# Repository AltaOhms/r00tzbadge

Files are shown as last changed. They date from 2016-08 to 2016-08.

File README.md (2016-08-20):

# r00tz badge 2016
Example code and eagle files for r00tz badge 2016

##To Solder the Badge
Under the [HookupGuide](https://github.com/HelloTechie/r00tzbadge/tree/master/HookupGuide) folder has the hook-up soldering guide.

##BOM - Bill of Materials

###[SparkFun](https://www.sparkfun.com)

* [SparkFun Redstick](https://www.sparkfun.com/products/13741)
* [LED Array](https://www.sparkfun.com/products/13795)
* [IR LED](https://www.sparkfun.com/products/9349)
* [4x Arduino Stackable Header - 6 pin](https://www.sparkfun.com/products/9280)
* [2x Momentary Pushbutton Switch - 12mm Square](https://www.sparkfun.com/products/9190)
* [BONUS: Thumb Joystick](https://www.sparkfun.com/products/9032)
* [BONUS: Joystick PCB](https://www.sparkfun.com/products/9110)

###[Pololu](https://www.pololu.com)

* [Battery Holder](https://www.pololu.com/product/1160)
* [Breakaway headers](https://www.pololu.com/product/965)

###[Digikey](http://www.digikey.com/) 

* [Standard Headers](http://www.digikey.com/product-detail/en/sullins-connector-solutions/PPTC121LFBN-RC/S6100-ND/807231)
* [IC IR RCVR MOD 38KHZ DOME RADIAL](http://www.digikey.com/scripts/DkSearch/dksus.dll?Detail&itemSeq=201968569&uq=636052976367495774)
* [56 Resistor](http://www.digikey.com/product-detail/en/stackpole-electronics-inc/CFM12JT56R0/S56HCT-ND/2617631)
* [330 ohm Resistor](http://www.digikey.com/product-detail/en/yageo/CFR-12JB-52-330R/330EBK-ND/4009)
* [ESD Bags](http://www.digikey.com/product-detail/en/scs/10046/SCP313-ND/1621588)

###Coding time!

####Redstick - An Arduino in a small form factor!
The Redstick [guide](https://learn.sparkfun.com/tutorials/redstick-hookup-guide?_ga=1.155838777.304927311.1426541708) is jammed packed with infomation on pin outs and how to get started coding!

If you are using Windows, you will need to install [FTDI Drivers](https://learn.sparkfun.com/tutorials/how-to-install-ftdi-drivers). 

####Arduino IDE
You will need to download the [Arduino IDE here](https://www.arduino.cc/en/Main/Software). Arduino is completely free and open source! What is great about the Arduino is that the community is huge and there is tons of example code and guides to help jump start your own projects. Included in this repo is [r00tz example code and libraries](https://github.com/HelloTechie/r00tzbadge/tree/master/Libraries). To learn how to add the r00tz arduino libraries, please follow this [tutorial](https://learn.sparkfun.com/tutorials/installing-an-arduino-library?_ga=1.197370157.304927311.1426541708).

Happy hacking!

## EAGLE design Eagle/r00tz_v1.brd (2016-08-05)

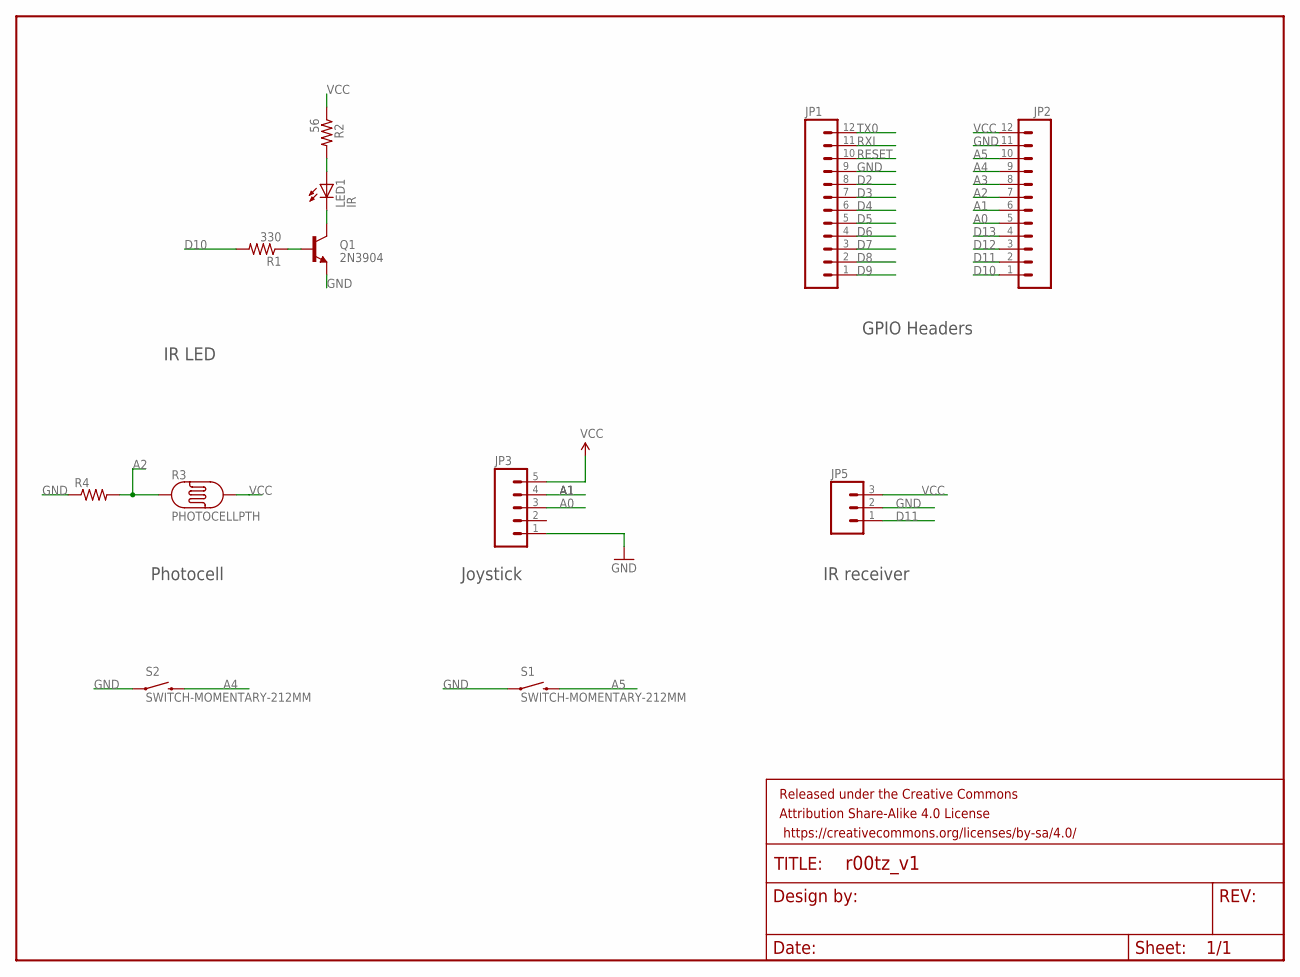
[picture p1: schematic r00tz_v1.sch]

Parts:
FRAME1: FRAME-LETTER; CREATIVE_COMMONS
JP1, JP2: M12PTH; 1X12
JP3: M05PTH; 1X05
JP5: M03PTH; 1X03
LED1: IR; LED5MM
Q1: 2N3904; TO-92
R1: 330; AXIAL-0.3
R2: 56; AXIAL-0.3
R3: PHOTOCELLPTH; PHOTOCELL
R4: 10KOHM-1/6W-5%(PTH)KIT; AXIAL-0.3-KIT
S1, S2: SWITCH-MOMENTARY-212MM; TACTILE-PTH-12MM

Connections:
A0: JP2.5, JP3.3
A1: JP2.6, JP3.4
A2: JP2.7, R3.1, R4.P$2 (2)
A3: JP2.8
A4: JP2.9, S2.3 (2)
A5: JP2.10, S1.3 (2)
D2: JP1.8
D3: JP1.7
D4: JP1.6
D5: JP1.5
D6: JP1.4
D7: JP1.3
D8: JP1.2
D9: JP1.1
D10: JP2.1, R1.P$2 (2)
D11: JP2.2, JP5.1
D12: JP2.3
D13: JP2.4
GND: JP1.9, JP2.11, JP3.1, JP5.2, Q1.1 (E), R4.P$1 (1), S1.1, S2.1
unnamed: LED1.K (C), Q1.3 (C)
unnamed: Q1.2 (B), R1.P$1 (1)
unnamed: LED1.A, R2.P$2 (2)
RESET: JP1.10
RXI: JP1.11
TX0: JP1.12
VCC: JP2.12, JP3.5, JP5.3, R2.P$1 (1), R3.2

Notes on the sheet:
GPIO Headers
Joystick
Photocell
IR LED
IR receiver

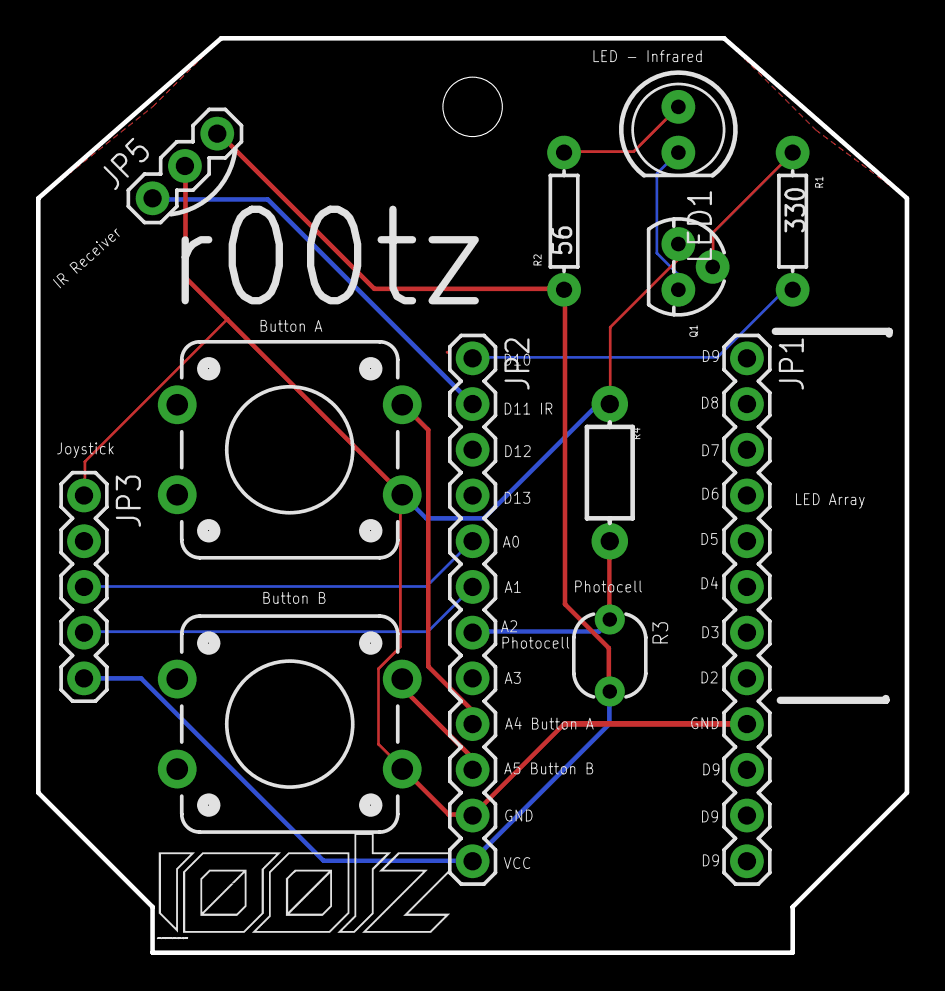
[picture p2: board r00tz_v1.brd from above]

Board: 2 copper layers, 48.3 x 50.8 mm, 14 parts (0 on the bottom side), 12 nets.

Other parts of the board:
U$1: STAND-OFF

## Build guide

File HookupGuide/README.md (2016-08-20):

##r00tz Badge

To get started: Follow along the [soldering guide](https://github.com/HelloTechie/r00tzbadge/blob/master/HookupGuide/rootzguidelow.pdf) and view the images below for additional guidance. If you are new to soldering, please read [How to Solder - Through-hole Soldering](https://learn.sparkfun.com/tutorials/how-to-solder---through-hole-soldering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) for tips and tricks! 

###Additional r00tz Badge Guidance

Solder 2x of the 12 pin female headers on top of the Redstick.

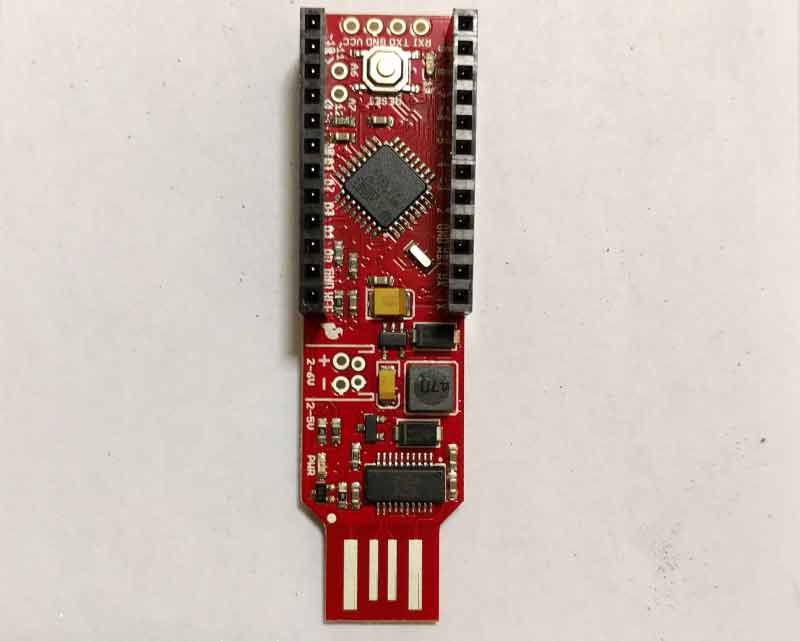
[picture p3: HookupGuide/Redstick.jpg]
RedStick Redstick


The 8 pin male header will be on the bottom of the LED Array.

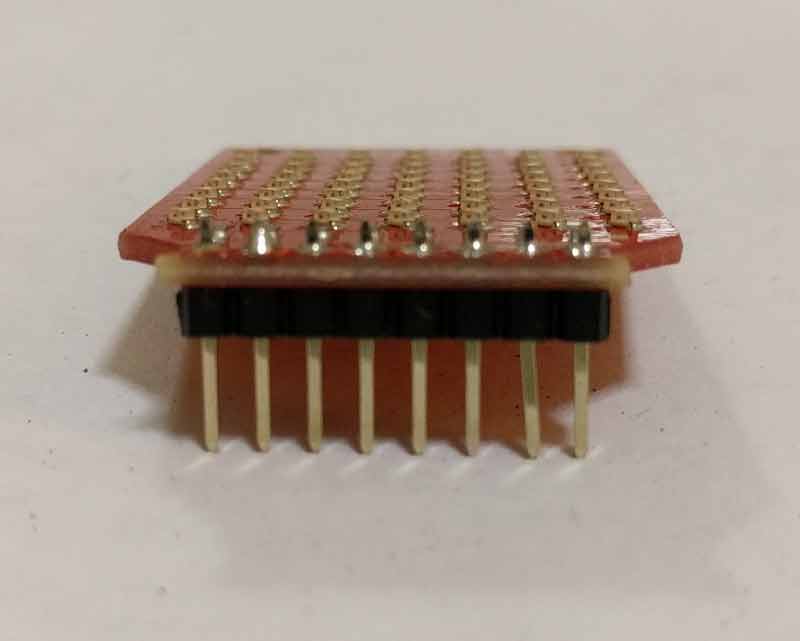
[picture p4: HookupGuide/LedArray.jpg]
LED Array


Do not cut the legs off of any the headers. The long headers are used for the r00tz shield PCB.

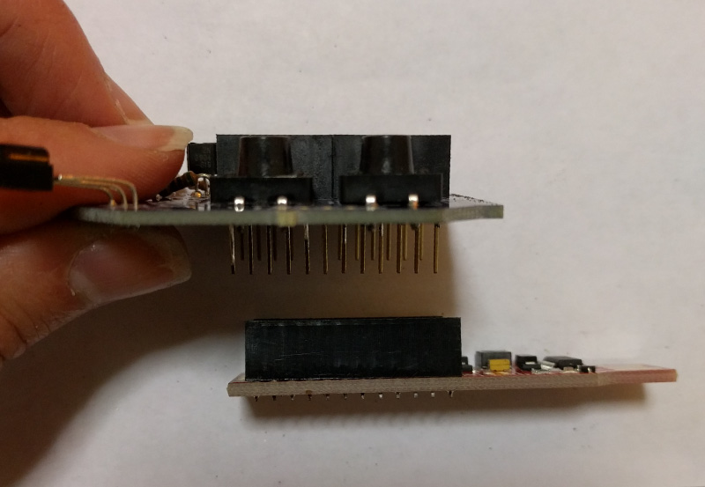
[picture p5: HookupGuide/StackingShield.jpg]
Stacking Shield How to stack the shield


After all parts are soldered on the shield you can then stack the r00tz shield on top of the Redstick's headers. Place the LED array on the correct pins of the r00tz shield. The r00tz shield has white silkscreen that says "LED ARRAY." Follow that for placement guidance. In order for the badge to work, you must have the shield & LED Array stacked correctly and look like the photo below.

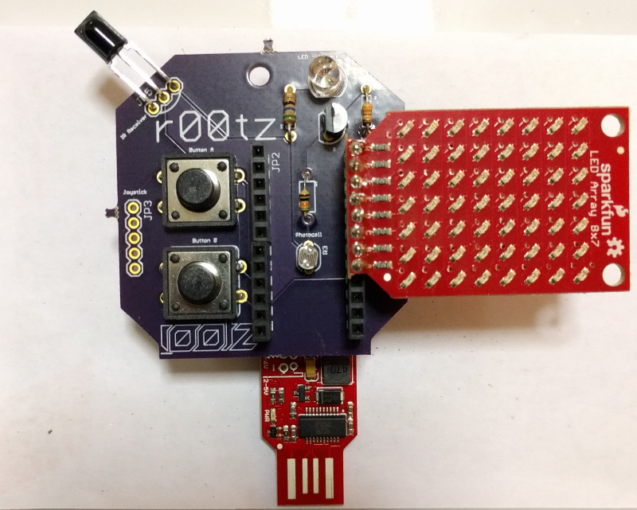
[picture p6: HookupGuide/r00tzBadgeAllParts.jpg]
Final Badge


Images aren't the best quality, but if you have questions please let me know.

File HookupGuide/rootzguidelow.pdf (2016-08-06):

# r00tz Badge Soldering Guide

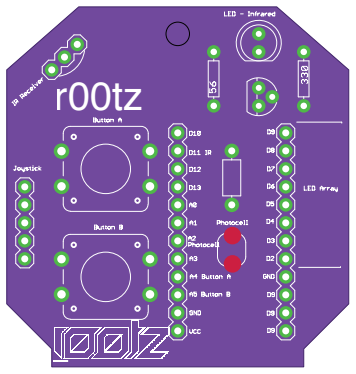
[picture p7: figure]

2:Insert photocell
through the top side
of the r00tz PCB.

Slightly bend the legs
outward to hold the
photocell in place.

Solder the legs on the
back side of the r00tz
PCB. After soldering
cut the long legs
(leads) off with the
wire cutters.

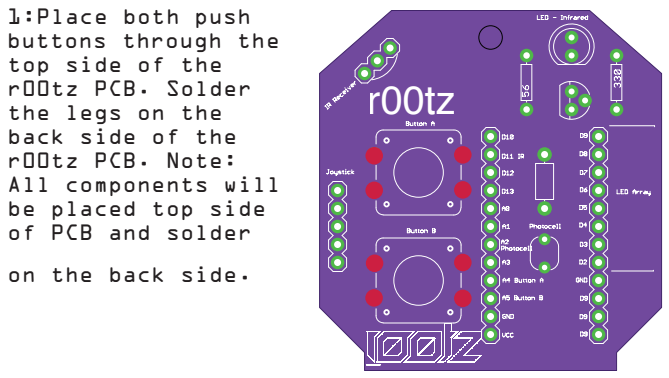
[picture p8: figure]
1:Place both push buttons through the top side of the r00tz PCB. Solder the legs on the back side of the r00tz PCB. Note: All components will be placed top side of PCB and solder; on the back side.
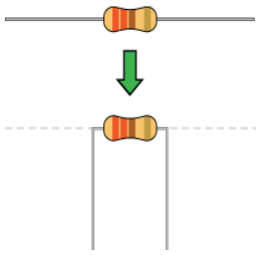
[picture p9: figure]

3:Bend resistor
legs into 90°
angles and place 3
resistors. Each
resistor has
different color
bands. Make sure
that each resistor
is in the right
spot. Cut away
excess legs.

# r00tz

4: Insert through the top and solder the IR receiver, IR LED, and transistor. EACH component needs to be placed in the correct direction. Polarized components only be connected to a circuit in one direction, so follow the silkscreen on how to place the component. Cut away excess legs.

# r00tz

+

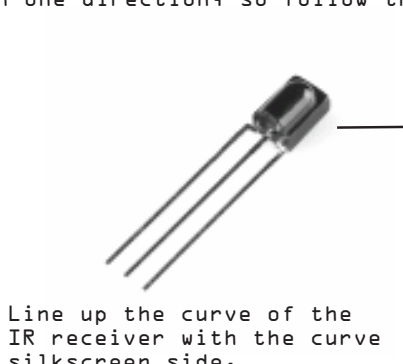
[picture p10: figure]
Line up the curve of the IR receiver with the curve

silkscreen side.

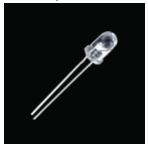
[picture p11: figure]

Line up with the
flat edge of transistor. The IR
receiver and transistor look alike,
so double check
before soldering.

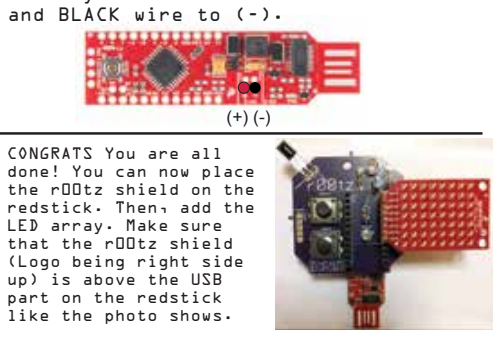
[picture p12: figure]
and BLACK wire to (-).; CONGRATS You are all done! You can now place the r00tz shield on the redstick. Then, add the LED array. Make sure that the r00tz shield (Logo being right side up) is above the USB part on the redstick like the photo shows.

## r00tz

5: Place and Solder headers. Do NOT cut legs off of the headers.

4x stackable headers
insert through TOP side
and solder on the BOTTOM.

8 pin male header insert
short leg side through
the BOTTOM of LED array
and solder the TOP side.

BONUS Joystick add-on (Limited qtys): Insert male header short leg side through bottom. Then, solder to top side. Place on the TOP side of r00tz PCB where it says joystick. Then, solder the bottom side.

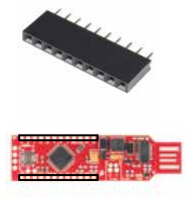
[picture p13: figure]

2x 8 pin female header
insert through the TOP
side of Redstick and
solder the BOTTOM side.

Battery Pack: Solder RED wire to (+)

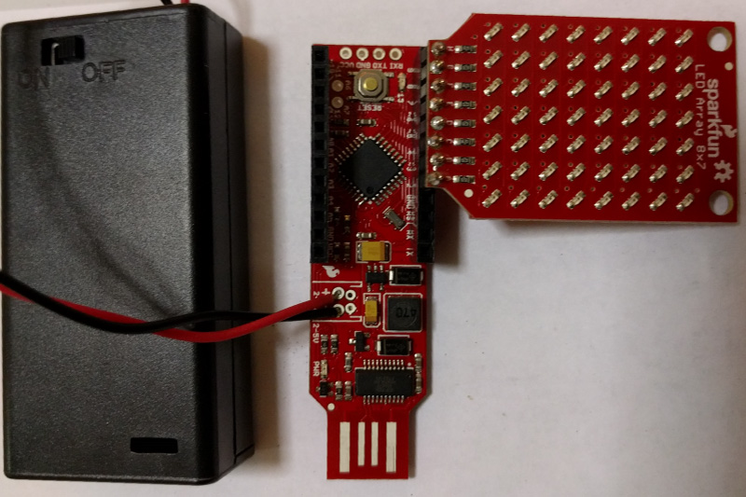
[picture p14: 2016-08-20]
HookupGuide/RedstickLedArrayCombo.jpg

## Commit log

2016-08-05 Example libraries
    LED array and IR
2016-08-05 Eagle files
    Board layout
    [r00tz_v1.brd, r00tz_v1.sch]
2016-08-06 Hookup Guide
    How to solder badge
2016-08-20 Soldering Badge Images
    Extra images for the soldering guide and where to stack the shield &
    Led Array on top of the Redstick

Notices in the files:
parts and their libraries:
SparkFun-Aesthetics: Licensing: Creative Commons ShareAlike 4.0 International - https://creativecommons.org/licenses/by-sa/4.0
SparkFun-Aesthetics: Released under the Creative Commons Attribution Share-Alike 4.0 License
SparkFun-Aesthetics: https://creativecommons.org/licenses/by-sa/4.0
